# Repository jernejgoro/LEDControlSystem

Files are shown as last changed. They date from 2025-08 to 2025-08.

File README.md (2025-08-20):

# LEDControlSystem

## Overview
The **LEDControlSystem** is an integrated solution designed to control up to six independent LEDs / LED strips. This project consists of four main components: two PCB projects called **LEDcontroller** and **OfflineFlyback**, **Firmware** for the LEDcontroller and a **Web Application** for controlling the system, providing users with a seamless and intuitive way to manage their LED lighting.

---

## Components

### 1. LEDcontroller
- **Description**: An LED controller based on the Espressif ESP-WROOM-32 module with six independent output channels.
  <details>
  <summary><strong>Characteristics:</strong></summary>

  - **Input voltage range:** 5 V<sub>DC</sub> - 36 V<sub>DC</sub>
  - **Output voltage:** same as input
  - **Number of independent channels:** 6
  - **Maximum output current per channel:** 3 A
  - **Maximum total output current:** 6,5 A
  </details>

  <details>
  <summary><strong>Features:</strong></summary>

  - Dedicated mode button
  - LED indicators: power, WiFi state, error
  - Connector for programming and debugging via UART
  </details>

### 2. OfflineFlyback
- **Description:** A 24 V / 55 W SMPS based on the STM VIPERGAN50 switcher and Wurth 750343068 transformer.
- **Topology:** Isolated quasi-resonant flyback with secondary side regulation.
  <details>
  <summary><strong>Characteristics:</strong></summary>

  - **Input voltage range:** 185 V<sub>AC</sub> - 265 V<sub>AC</sub>
  - **Output voltage:** 24 V<sub>DC</sub>
  - **Maximum output power:** 55 W
  - **Efficiency at full load:** Up to 90%
  - **Idle power consumption:** < 100 mW (@ 230 V<sub>AC</sub>)
  - **Output ripple and noise:** < 70 mV<sub>pp</sub>
  </details>

  <details>
  <summary><strong>Features:</strong></summary>

  - Compact design
  - Input overvoltage protection
  - Brown-in and brown-out
  - Output overvoltage protection
  - Output overload protection
  - Embedded thermal shutdown
  </details>

### 3. Firmware
- **Description**: Custom firmware based on the ESP-IDF framework 5.4.0 and FreeRTOS designed for the LEDcontroller.
  <details>
  <summary><strong>Features:</strong></summary>

  - **Supports various LED configurations**: single-color LEDs and RGB LEDs
  - **Channel dimming method:** PWM (10 bit, 5 kHz)
  - **Smooth transitions**: seamless changes when altering the state of the output channels
  - **Supports three different WiFi modes**: disabled, client mode and access point mode
  - **Custom web API**: used to change device settings and control output channels
  </details>

### 4. Web Application
- **Description**: A user-friendly web application that allows users to interact with the LEDcontroller.
  <details>
  <summary><strong>Features:</strong></summary>

  - Real-time control of output channels
  - Real-time control of device settings via the "admin" webpage
  - Compatible with various devices (PC, tablet, smartphone)
  </details>

---

## Web API

#### GET method: 

<details>
<summary><strong>Reading device configuration:</strong></summary>

| Description | URL | Query string supported names |
|-|-|-|
| Full device configuration | http://\<_IP_>/api/conf | / |
| Number of active RGB LEDs | http://\<_IP_>/api/conf | rgb_outputs |
| Number of active single-color LEDs | http://\<_IP_>/api/conf | w_outputs |
| WiFi enable flag at device startup | http://\<_IP_>/api/conf | enable_wifi |

</details>

<details>
<summary><strong>Reading output channel status and duty cycle:</strong></summary>

| Description | URL | Query string supported names |
|-|-|-|
| Enable status and duty cycle of all active channels | http://\<_IP_>/api/ch | / |
| Enable status and duty cycle of all active channels | http://\<_IP_>/api/ch/all | / |
| Enable status of all active channels | http://\<_IP_>/api/ch/all | ch_enable |
| Duty cycle of all active channels | http://\<_IP_>/api/ch/all | ch_duty |
| Enable status of individual active channel | http://\<_IP_>/api/ch | ch<_0-5_>_enable |
| Duty cycle of individual active channel | http://\<_IP_>/api/ch | ch<_0-5_>_duty |

</details>

#### POST method: 

<details>
<summary><strong>Changing device configuration:</strong></summary>

| Description | URL | JSON key | Supported value |
|-|-|-|-|
| Number of active RGB LEDs | http://\<_IP_>/api/conf | rgb_outputs | 0 - 2 |
| Number of active single-color LEDs | http://\<_IP_>/api/conf | w_outputs | 0 - 6 |
| WiFi enable flag at device startup | http://\<_IP_>/api/conf | enable_wifi | 0, 1  |

</details>

<details>
<summary><strong>Changing WiFi credentials for client mode:</strong></summary>

| Description | URL | JSON key | Supported value |
|-|-|-|-|
| SSID | http://\<_IP_>/api/cred | WIFI_SSID | String up to 30 characters |
| Password | http://\<_IP_>/api/cred | WIFI_PASSWORD | String up to 30 characters |

</details>

<details>
<summary><strong>Changing output channel status and duty cycle:</strong></summary>

| Description | URL | JSON key | Supported value |
|-|-|-|-|
| Enable status of all active channels | http://\<_IP_>/api/ch/all | ch_enable | 0, 1 |
| Duty cycle of all active channels | http://\<_IP_>/api/ch/all | ch_duty | 0 - 1023 |
| Enable status of individual active channel | http://\<_IP_>/api/ch | ch<_0-5_>_enable | 0, 1 |
| Duty cycle of individual active channel | http://\<_IP_>/api/ch | ch<_0-5_>_duty | 0 - 1023 |

</details>

---

**Disclaimer:** This project is a work in progress. Use the files, hardware and software given in this repository **at your own risk**.

---

## License
This project (LEDControlSystem) is licensed under the GNU General Public License v3.0 - see the [LICENSE](LICENSE) file for details.

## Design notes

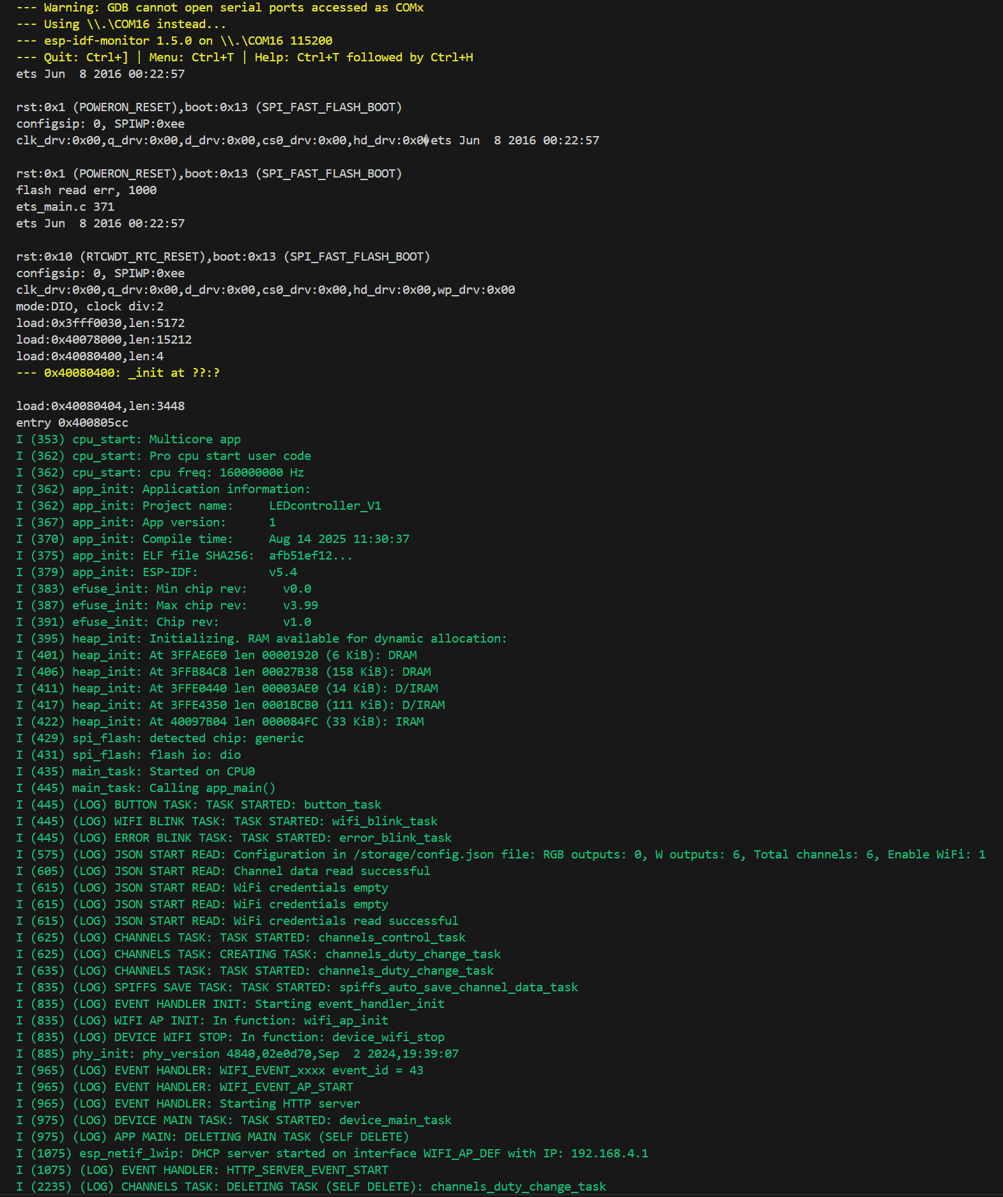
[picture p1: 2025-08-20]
firmware/LEDcontroller_V1.2.0/misc/LEDcontroller_V1.2.0_first_bootup_process.png

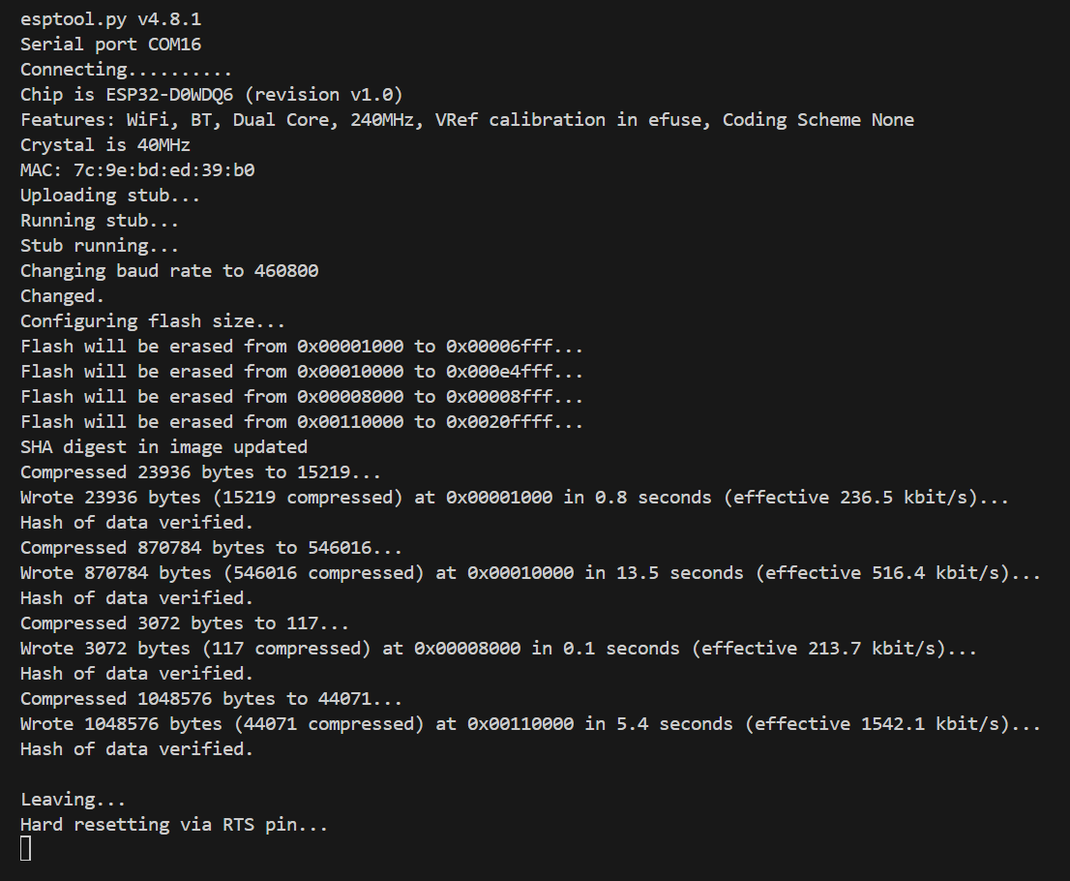
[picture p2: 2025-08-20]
firmware/LEDcontroller_V1.2.0/misc/LEDcontroller_V1.2.0_upload_process.png

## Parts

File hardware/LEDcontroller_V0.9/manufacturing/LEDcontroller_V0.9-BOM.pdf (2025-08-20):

Comment | Description | Designator | Footprint | LibRef | Quantity | Unit price /€ | Total price /€ | Unit price 10# /€ | Total price #10 /€
100n | Vishay GA0603Y104KXAAC31G | C1, C6, C7 | capacitor_smd_0603 | Capacitor - non-polarised | 3 | 0,266 | 0,80 | 0,169 | 0,51
10u | Samsung CL31B106KBHNNNE | C2 | capacitor_smd_1206 | Capacitor - non-polarised | 1 | 0,219 | 0,22 | 0,143 | 0,14
22u | TDK C2012X5R1V226M125AC | C3, C4 | capacitor_smd_0805 | Capacitor - non-polarised | 2 | 0,551 | 1,10 | 0,365 | 0,73
10u | TAIYO YUDEN TMK212BBJ106MGHT | C5 | capacitor_smd_0805 | Capacitor - non-polarised | 1 | 0,238 | 0,24 | 0,123 | 0,12
330u | Panasonic EEU-FS1V331LB | C8, C9 | capacitor_tht_3mm5_lead_8mm | Capacitor - polarised | 2 | 0,656 | 1,31 | 0,433 | 0,87
CDSOD323-T03SC | Bourns CDSOD323-T03SC | D1 | diode_smd_sod_323-2 | ESD diode | 1 | 0,665 | 0,67 | 0,500 | 0,50
green | Osram KG EELP41.22-PHRH-35-A8J8-20-R18 | D2 | led_smd_0603 | LED | 1 | 0,238 | 0,24 | 0,131 | 0,13
blue | ROHM SMLEN3BC8TT86 | D3 | led_smd_0603 | LED | 1 | 0,675 | 0,68 | 0,405 | 0,41
red | Osram KS EELP41.22-P1R2-58-A8J8-020-R18 | D4 | led_smd_0603 | LED | 1 | 0,238 | 0,24 | 0,131 | 0,13
Fuse | Bourns SF-0603HI800M-2 | F1 | resisitor_smd_0603 | Fuse | 1 | 0,466 | 0,47 | 0,413 | 0,41
15u | Bourns SRR5828A-150M | L1 | inductor_smd_5mm8_x_5mm8 | Inductor | 1 | 1,100 | 1,10 | 0,851 | 0,85
Terminal Block | Adam Tech EBAFA-02-D | P1 | terminal_block_1X2_5mm08 | Terminal Block 1X2 | 1 | 0,760 | 0,76 | 0,293 | 0,29
Terminal Block | 4x Adam Tech EBAFA-02-D | P2 | terminal_block_1X8_5mm08 | Terminal Block 1X8 | 1 | 0,760 | 0,76 | 0,293 | 0,29
Header | | P3 | header_2X3_2mm54 | Header 2X3 | 1 | | 0,00 | | 0,00
NMOS | ONSEMI FDS8949 | Q1, Q2, Q3 | generic_SO-8 | Transistor - N-MOSFET 2 ch | 3 | 1,490 | 4,47 | 0,903 | 2,71
86.6k | Panasonic ERA-3AEB8662V | R1 | resisitor_smd_0603 | Resistor | 1 | 0,095 | 0,10 | 0,055 | 0,06
30k | Panasonic ERA-3APB303V | R2 | resisitor_smd_0603 | Resistor | 1 | 0,238 | 0,24 | 0,201 | 0,20
10k | Vishay CRCW060310K0FKEI | R3 | resisitor_smd_0603 | Resistor | 1 | 0,114 | 0,11 | 0,028 | 0,03
10R | Vishay CRCW060310R0FKED | R4, R5, R6, R7, R8, R9 | resisitor_smd_0603 | Resistor | 6 | 0,114 | 0,68 | 0,028 | 0,17
1k | Vishay CRCW06031K00FKED | R10, R11, R12 | resisitor_smd_0603 | Resistor | 3 | 0,103 | 0,31 | 0,028 | 0,08
Tactile switch | Same Sky TS04-66-43-BK-160-SMT | S2 | tactile_switch_smd_6x6mm_5mm_4_pin | Switch - 4 pins V2 | 1 | 0,181 | 0,18 | 0,147 | 0,15
Test point | | TP1 | test_point | Test point | 1 | | 0,00 | | 0,00
STM DCP3601 | STM DCP3601NDMR | U1 | generic_sot23-6L | STM DCP3601 | 1 | 1,880 | 1,88 | 1,210 | 1,21
ESP-WROOM-32 | Espressif ESP-WROOM-32 | U2 | ESP-WROOM-32_no_silk | ESP-WROOM-32 | 1 | | 0,00 | | 0,00
ESDA25B1RL | STM ESDA25B1RL | U3 | generic_SO-8 | ESD diodes - 6 channels | 1 | 0,447 | 0,45 | 0,333 | 0,33
PESD3V3L5UY | Nexperia PESD3V3L5UY,115 | U5 | GENERIC_SOT363 | ESD diodes - 5 channels | 1 | 0,295 | 0,30 | 0,200 | 0,20
| | | | | | | #1 | #10
VAT /% | 22
| | | | | | | 17,28 | 10,52
| | | | | | | 3,80 | 2,31
| | | | | | | 21,09 | 12,84

Source: eu.mouser.com, date: 21. 3. 2025

Price - SUM /€
Price - VAT /€
Price - Total (SUM + VAT) /€

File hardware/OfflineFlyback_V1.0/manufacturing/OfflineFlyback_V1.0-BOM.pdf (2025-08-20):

Comment | Description | Designator | Footprint | LibRef | Quantity | Unit price /€ | Total price /€ | Unit price 10# /€ | Total price #10 /€
Bridge Rectifier 2A | Bourns CD-MBL210SL | BR1 | full_bridge_rectifier_SMD | Bridge Rectifier | 1 | 0,513 | 0,513 | 0,355 | 0,355
4n7 | TDK CD12ZU2GA472MYNKA Y1 | C1 | capacitor_tht_10mm_lead_2_slim | Capacitor - non-polarised | 1 | 0,576 | 0,576 | 0,386 | 0,386
68u | Panasonic EEU-EE2G680 | C2, C3 | capacitor_tht_7mm5_lead_18mm | Capacitor - polarised | 2 | 2,580 | 5,160 | 1,760 | 3,520
100n | Vishay / BC Components BFC233920104 X2 | C4, C5 | capacitor_tht_10mm_lead | Capacitor - non-polarised | 2 | 0,387 | 0,774 | 0,195 | 0,390
820u | Panasonic EEU-FR1V821L | C6, C7 | capacitor_tht_5mm_lead_10mm | Capacitor - polarised | 2 | 0,990 | 1,980 | 0,508 | 1,016
4n7 | Kyocera AVX 1206AC472KAT2A X7R | C8 | capacitor_smd_1206 | Capacitor - non-polarised | 1 | 0,369 | 0,369 | 0,220 | 0,220
10u | Samsung CL31B106KBHNNNE X7R | C9 | capacitor_smd_1206 | Capacitor - non-polarised | 1 | 0,180 | 0,180 | 0,108 | 0,108
22u | Wurth 860240673003 | C10 | capacitor_tht_2mm5_lead_6mm3 | Capacitor - polarised | 1 | 0,162 | 0,162 | 0,162 | 0,162
220p | Samsung CL10B221KC8WPNC X7R | C11 | capacitor_smd_0603 | Capacitor - non-polarised | 1 | 0,099 | 0,099 | 0,059 | 0,059
1u | Samsung CL10B105KB9VPJC X7R | C12 | capacitor_smd_0603 | Capacitor - non-polarised | 1 | 0,342 | 0,342 | 0,223 | 0,223
100n | Vishay / Vitramon GA0603Y104KXAAC31G X7R | C13 | capacitor_smd_0603 | Capacitor - non-polarised | 1 | 0,270 | 0,270 | 0,160 | 0,160
22n | Kyocera AVX 06035C223K4T2A X7R | C14 | capacitor_smd_0603 | Capacitor - non-polarised | 1 | 0,090 | 0,090 | 0,031 | 0,031
1n | Murata GRM1885C1H102JA01D C0G | C15 | capacitor_smd_0603 | Capacitor - non-polarised | 1 | 0,090 | 0,090 | 0,018 | 0,018
10n | Murata GCM188R71H103KA37J X7R | C16 | capacitor_smd_0603 | Capacitor - non-polarised | 1 | 0,090 | 0,090 | 0,045 | 0,045
10A | Panjit MBR10H150PC-AU_R2_007A1 | D1 | diode_TO_2787C | Diode - Schottkey | 1 | 0,828 | 0,828 | 0,560 | 0,560
300mA | Vishay 1N4148W-HG3_A-08 | D2 | diode_smd_sod_123 | Diode - silicon | 1 | 0,297 | 0,297 | 0,208 | 0,208
1kV 2A | MCC FR2M-LTP | D3 | diode_smd_smb | Diode - silicon | 1 | 0,594 | 0,594 | 0,348 | 0,348
3.15 A | Littelfuse 40013150440 3.15 A Slow Blow | F1 | fuse_tht_5mm08 | Fuse | 1 | 1,320 | 1,320 | 1,110 | 1,110
744821240 | Wurth 744821240 1.5A 4mH | L1 | wurth_common_mode_choke_4mm5_10mm | Common Mode Choke | 1 | 2,470 | 2,470 | 2,450 | 2,450
3u3 | Bourns SRP7028A-3R3M | L2 | inductor_smd_6mm6_x_7mm3 | Inductor | 1 | 0,828 | 0,828 | 0,704 | 0,704
Terminal Block | Adam Tech EBAFA-02-D | P1, P2 | terminal_block_1X2_5mm08 | Terminal Block 1X2 | 2 | 0,585 | 1,170 | 0,433 | 0,866
2M | Vishay / Draloric RCV12062M00JNEA | R1 | resisitor_smd_1206 | Resistor | 1 | 0,216 | 0,216 | 0,110 | 0,110
62k | Panasonic ERJ-UP8F6202V | R2, R3 | resisitor_smd_1206 | Resistor | 2 | 0,225 | 0,450 | 0,080 | 0,160
10M | ROHM KTR25JZPF1005 | R4 | resisitor_smd_1210 | Resistor | 1 | 0,297 | 0,297 | 0,135 | 0,135
10R | Vishay CRCW060310R0FKED | R5 | resisitor_smd_0603 | Resistor | 1 | 0,135 | 0,135 | 0,068 | 0,068
820k | Walsin MR06X8203FTL | R6 | resisitor_smd_0603 | Resistor | 1 | 0,140 | 0,140 | 0,022 | 0,022
510k | Bourns CR0603-FX-5103ELF | R7 | resisitor_smd_0603 | Resistor | 1 | 0,090 | 0,090 | 0,020 | 0,020
1k6 | Bourns CR0603-FX-1601ELF | R8 | resisitor_smd_0603 | Resistor | 1 | 0,090 | 0,090 | 0,012 | 0,012
130k | Panasonic ERJ-3RED1303V 0.5% | R9, R13 | resisitor_smd_0603 | Resistor | 2 | 0,126 | 0,252 | 0,125 | 0,250
10k | Vishay / Dale CRCW060310K0FKEI | R10 | resisitor_smd_0603 | Resistor | 1 | 0,135 | 0,135 | 0,068 | 0,068
0R | Royalohm CQ03WAF0000T5E | R11 | resisitor_smd_0603 | Resistor | 1 | 0,001 | 0,001 | 0,001 | 0,001
7k68 | Panasonic ERA-3AEB7681V 0.1% | R12 | resisitor_smd_0603 | Resistor | 1 | 0,090 | 0,090 | 0,049 | 0,049
100k | Yageo AC0603FR-7W100KL | R14 | resisitor_smd_0603 | Resistor | 1 | 0,243 | 0,243 | 0,024 | 0,024
47k | Bourns CR0603-FX-4702ELF | R15 | resisitor_smd_0603 | Resistor | 1 | 0,090 | 0,090 | 0,014 | 0,014
88k7 | Walsin WR06X8872FTL | R16 | resisitor_smd_0603 | Resistor | 1 | 0,140 | 0,140 | 0,025 | 0,025
15k | DO NOT PLACE | R17 | resisitor_smd_0603 | Resistor | 1 | | 0,000 | | 0,000
30k | Wurth 560112116107 | R18 | resisitor_smd_0603 | Resistor | 1 | 0,099 | 0,099 | 0,092 | 0,092
NTC 2R2 | Epcos / TDK B57237S0229M000 | RT1 | thermistor_tht_7mm5 | Thermistor | 1 | 0,855 | 0,855 | 0,788 | 0,788
275V 25A | Epcos / TDK B72210S0271K101 | RV1 | varistor_tht_7mm5 | Varistor | 1 | 0,504 | 0,504 | 0,257 | 0,257
WURTH_750343004 | | T1 | WURTH_10_PIN_750343004 | Wurth - 10 pins - 750343004 | 1 | 8,940 | 8,940 | 8,060 | 8,060
VIPERGAN50 | | U1 | VIPERGAN50TR_V2 | VIPERGAN50 V3 | 1 | 3,070 | 3,070 | 2,310 | 2,310
63% - 125% | Vishay VO615C-2X019T | U2 | SMD-4 | Optocoupler | 1 | 0,720 | 0,720 | 0,499 | 0,499
1.24V | STM TS3431AILT | VR1 | generic_sot23-3L | Programmable Shunt Voltage Reference | 1 | 1,060 | 1,060 | 0,648 | 0,648
| | | | | | | #1 | #10
VAT /% | 22
| | | | | | | 35,82 | 26,55
| | | | | | | 7,88 | 5,84
Price - Total (SUM + VAT) /€ | 43,70 | 32,39

Source: eu.mouser.com, date: 24. 6. 2025

Price - SUM /€
Price - VAT /€

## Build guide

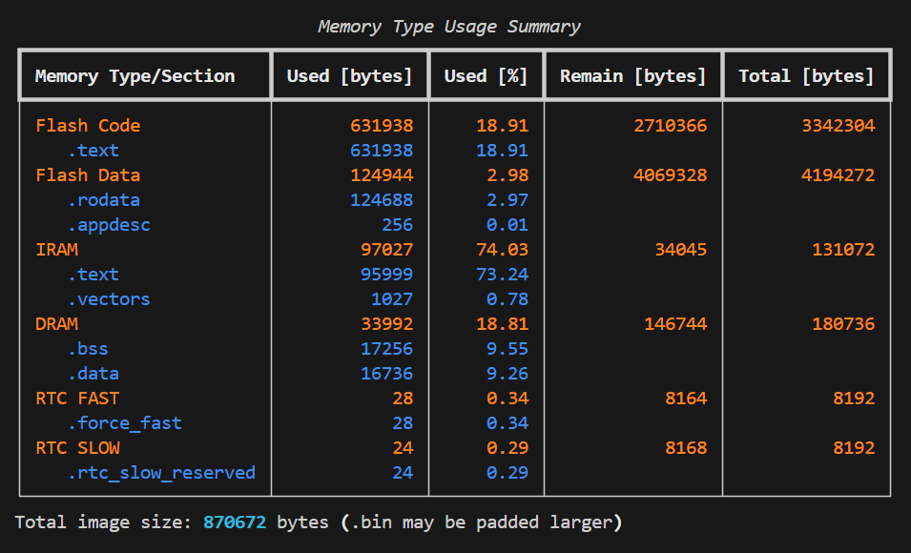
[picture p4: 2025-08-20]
firmware/LEDcontroller_V1.2.0/misc/LEDcontroller_V1.2.0_memory_usage.png

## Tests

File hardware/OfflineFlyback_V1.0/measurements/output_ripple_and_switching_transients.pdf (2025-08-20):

## Output ripple and switching transients

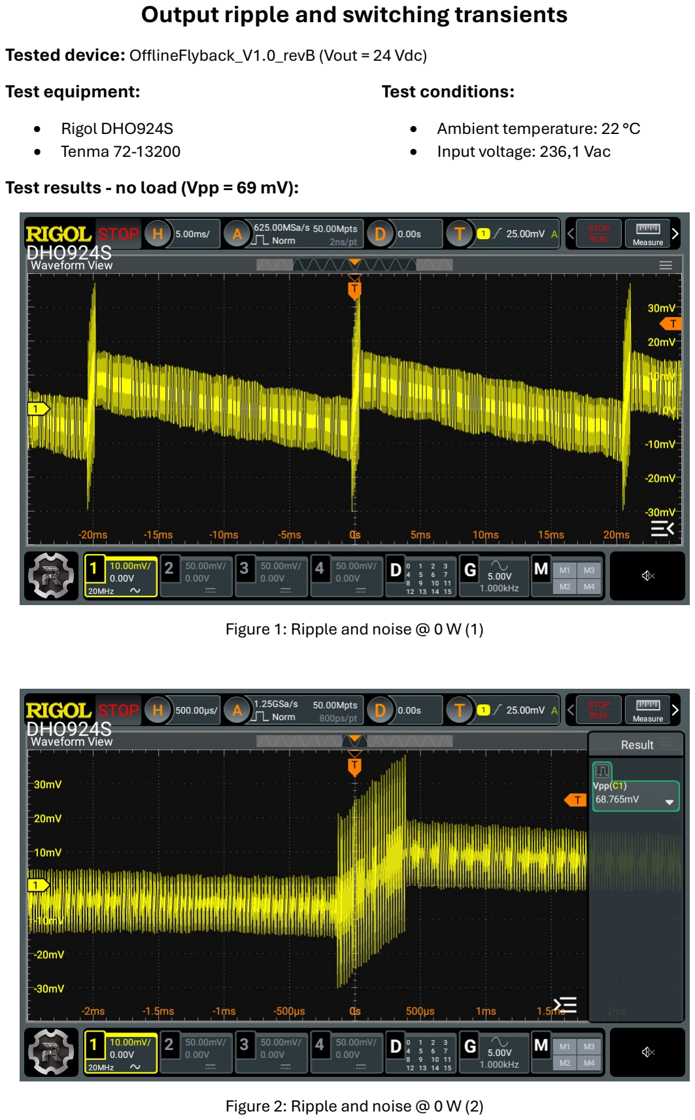
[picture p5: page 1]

Tested device: OfflineFlyback_V1.0_revB (Vout = 24 Vdc) Test equipment:

- Rigol DHO924S
- Tenma 72-13200

Test conditions:

- Ambient temperature: 22 °C
- Input voltage: 236,1 Vac Test results - no load (Vpp = 69 mV):

Figure 1: Ripple and noise @ 0 W (1)

Figure 2: Ripple and noise @ 0 W (2)

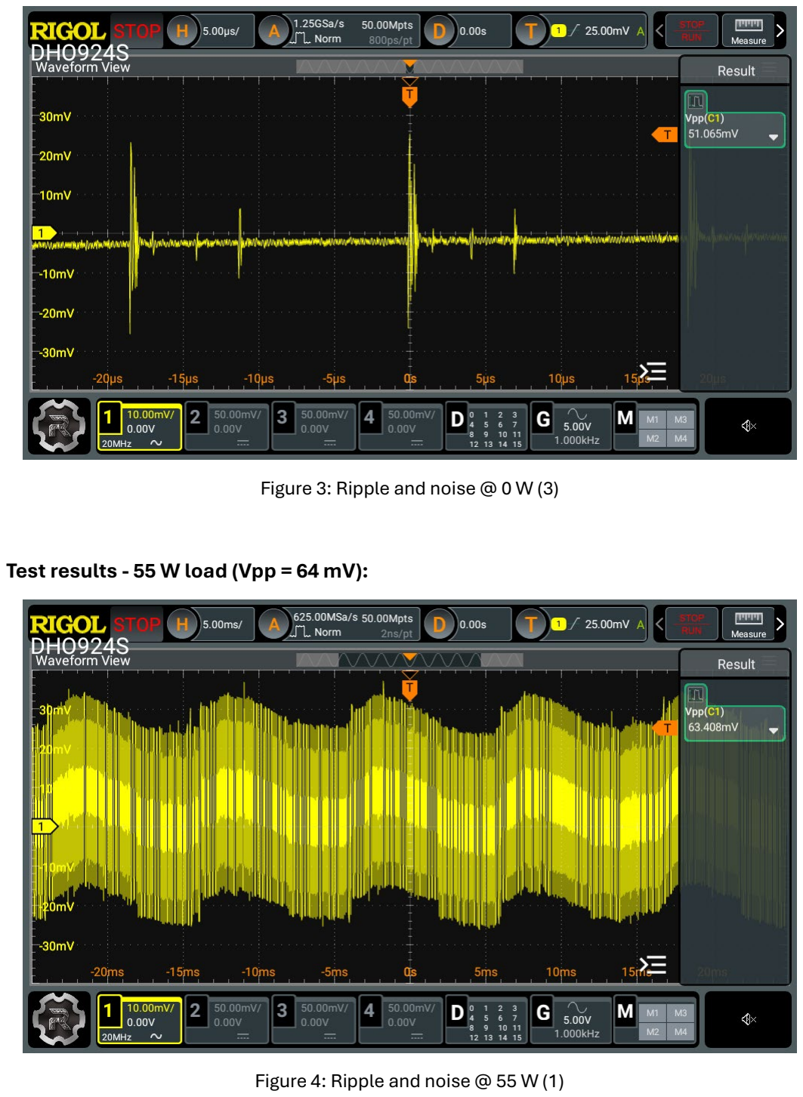
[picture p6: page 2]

Figure 3: Ripple and noise @ 0 W (3)

Test results - 55 W load (Vpp = 64 mV):

Figure 4: Ripple and noise @ 55 W (1)

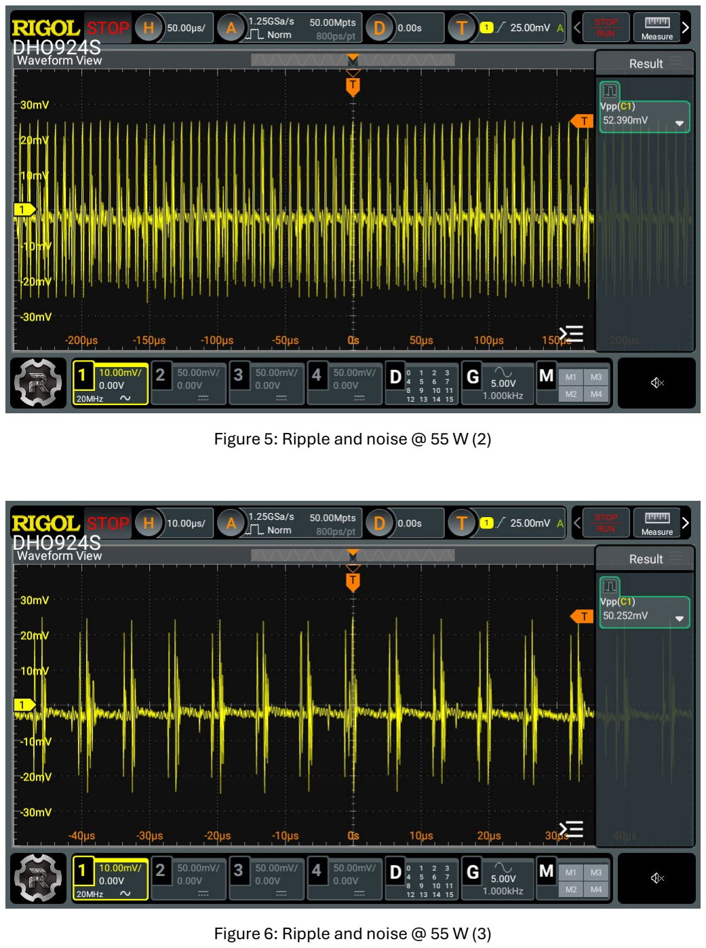
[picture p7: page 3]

Figure 5: Ripple and noise @ 55 W (2)

Figure 6: Ripple and noise @ 55 W (3)

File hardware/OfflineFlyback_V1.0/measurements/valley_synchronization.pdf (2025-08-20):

## Valley synchronization

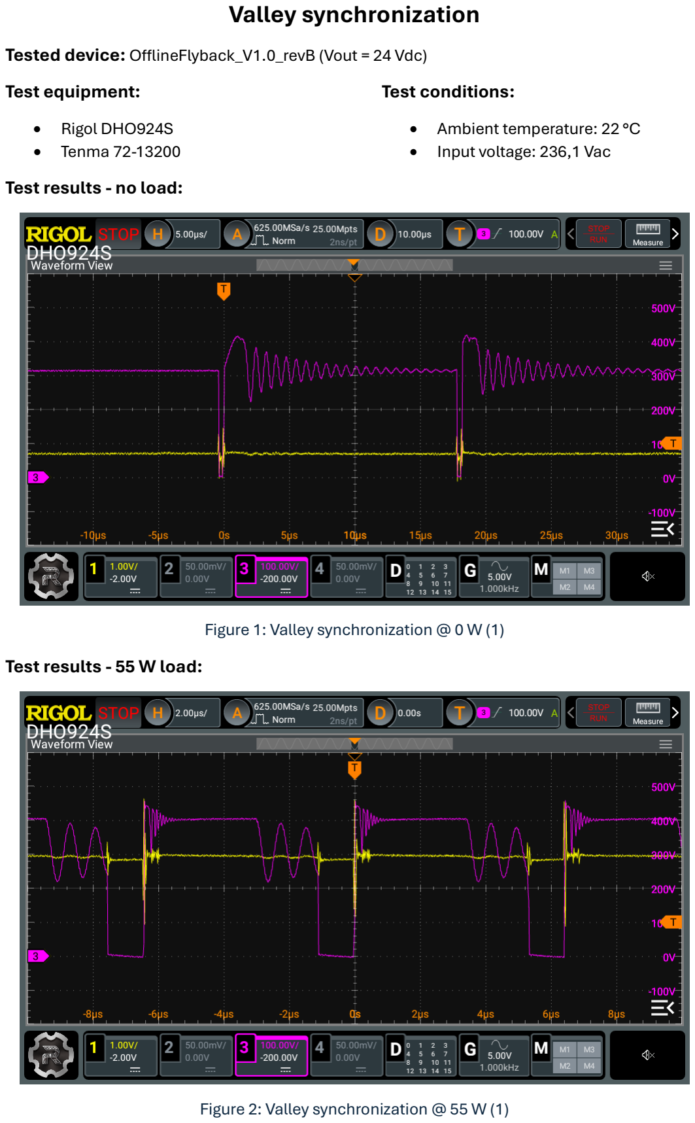
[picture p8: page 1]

Tested device: OfflineFlyback_V1.0_revB (Vout = 24 Vdc) Test equipment:

- Rigol DHO924S
- Tenma 72-13200

Test conditions:

- Ambient temperature: 22 °C
- Input voltage: 236,1 Vac Test results - no load:

Figure 1: Valley synchronization @ 0 W (1) Test results - 55 W load:

Figure 2: Valley synchronization @ 55 W (1)

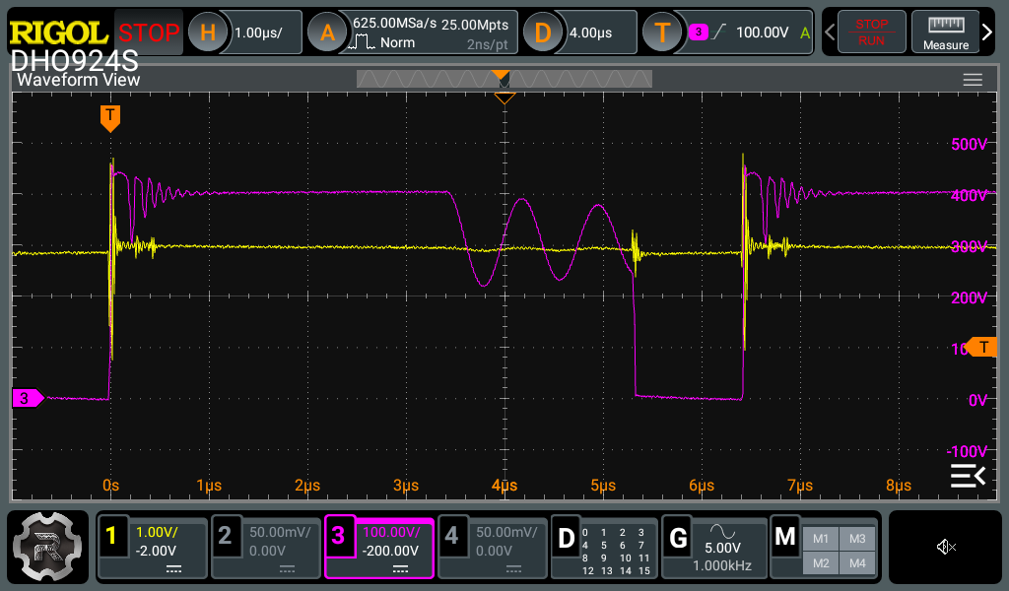
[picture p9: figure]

Figure 3: Valley synchronization @ 55 W (2)

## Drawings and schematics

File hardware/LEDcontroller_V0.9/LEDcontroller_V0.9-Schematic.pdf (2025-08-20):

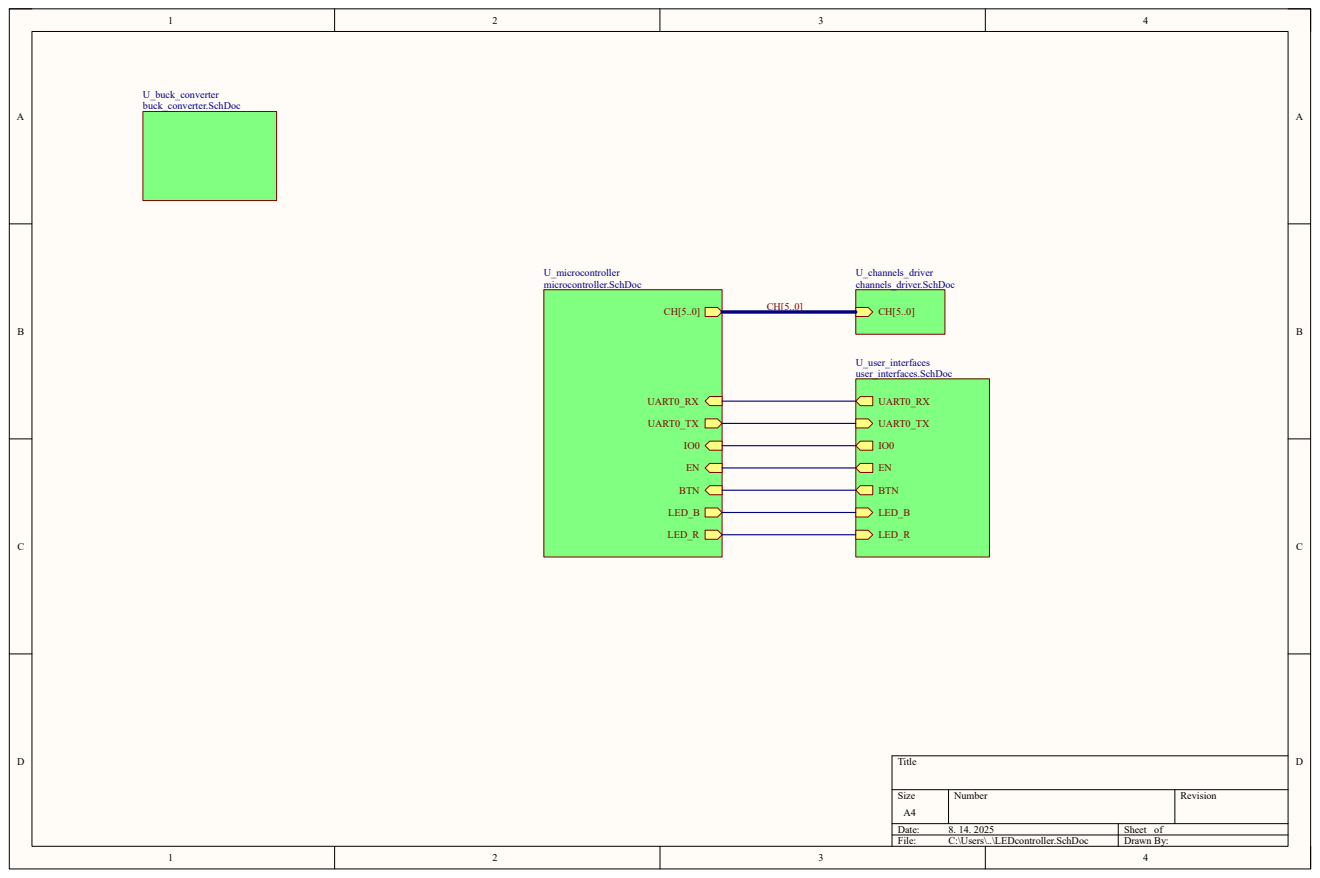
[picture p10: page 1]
Title; U_buck_converter buck_converter.SchDoc; UART0_TX; UART0_RX; BTN; LED_R; LED_B; U_microcontroller microcontroller.SchDoc; U_channels_driver channels_driver.SchDoc; U_user_interfaces user_interfaces.SchDoc

Size A4 | Number | Revision

Date: 8. 14. 2025 | Sheet of
File: C:\Users\..\LEDcontroller.SchDoc | Drawn By:

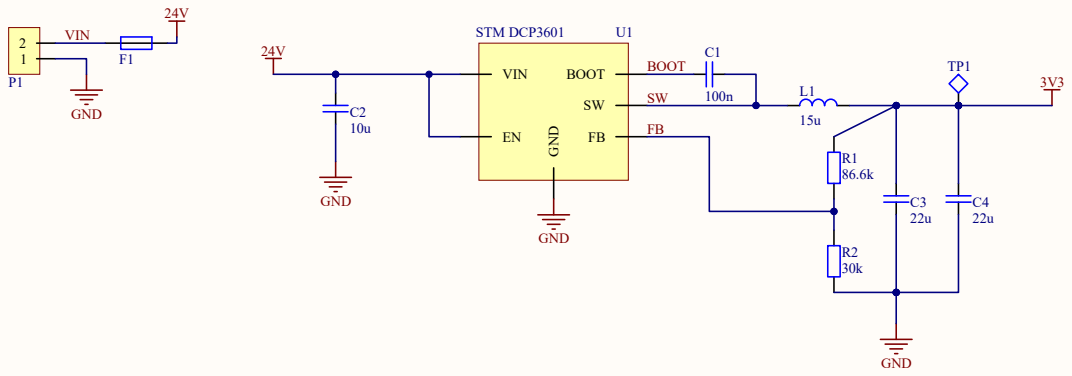
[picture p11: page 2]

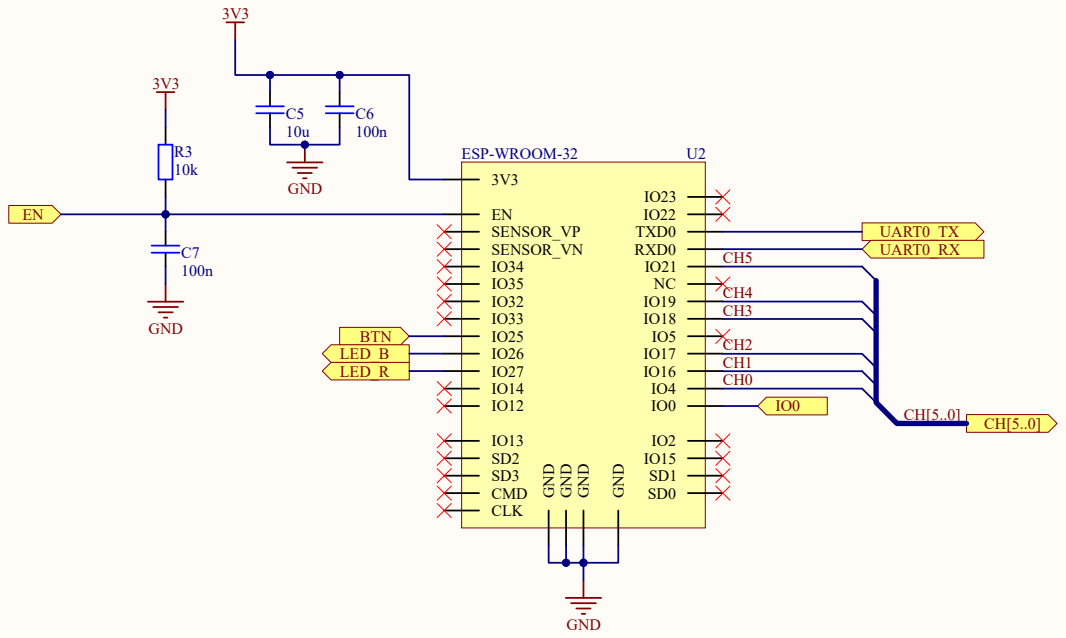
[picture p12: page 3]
Title; Size; Number; Revision; File:; C:\Users\..\microcontroller.SchDoc; Drawn By:; GND; EN SENSOR_VP SENSOR_VN IO34 IO35 IO32 IO33 IO25 IO26 IO27 IO14 IO12; IO13 SD2 SD3 CMD CLK; RXD0; TXD0; ESP-WROOM-32; UART0_TX UART0_RX; BTN LED_B LED_R

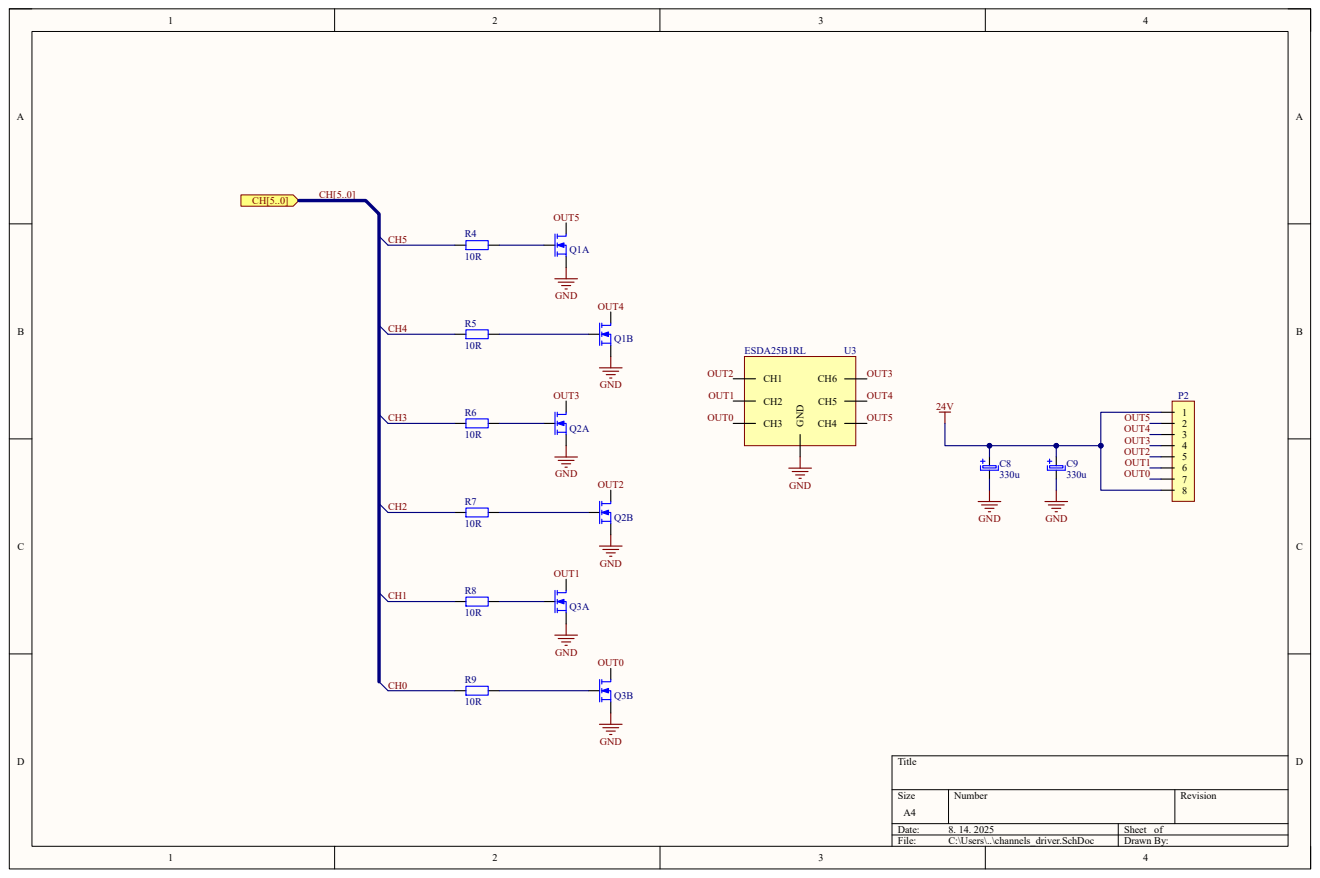
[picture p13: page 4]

# PROGRAMMING PORT

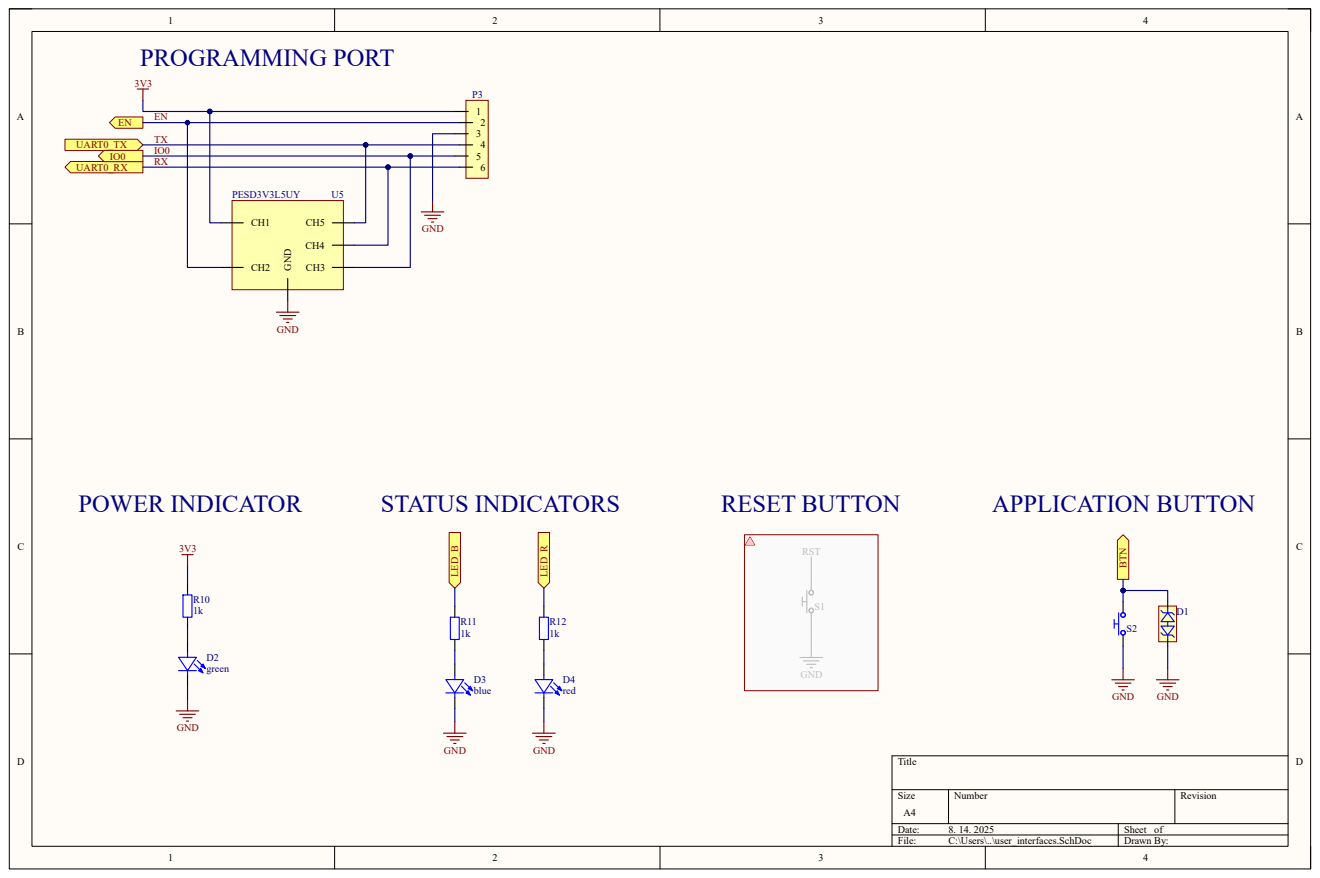
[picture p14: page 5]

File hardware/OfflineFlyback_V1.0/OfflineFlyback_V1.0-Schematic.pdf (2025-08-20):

## INPUT STAGE

HIGH VOLTAGE | LOW VOLTAGE

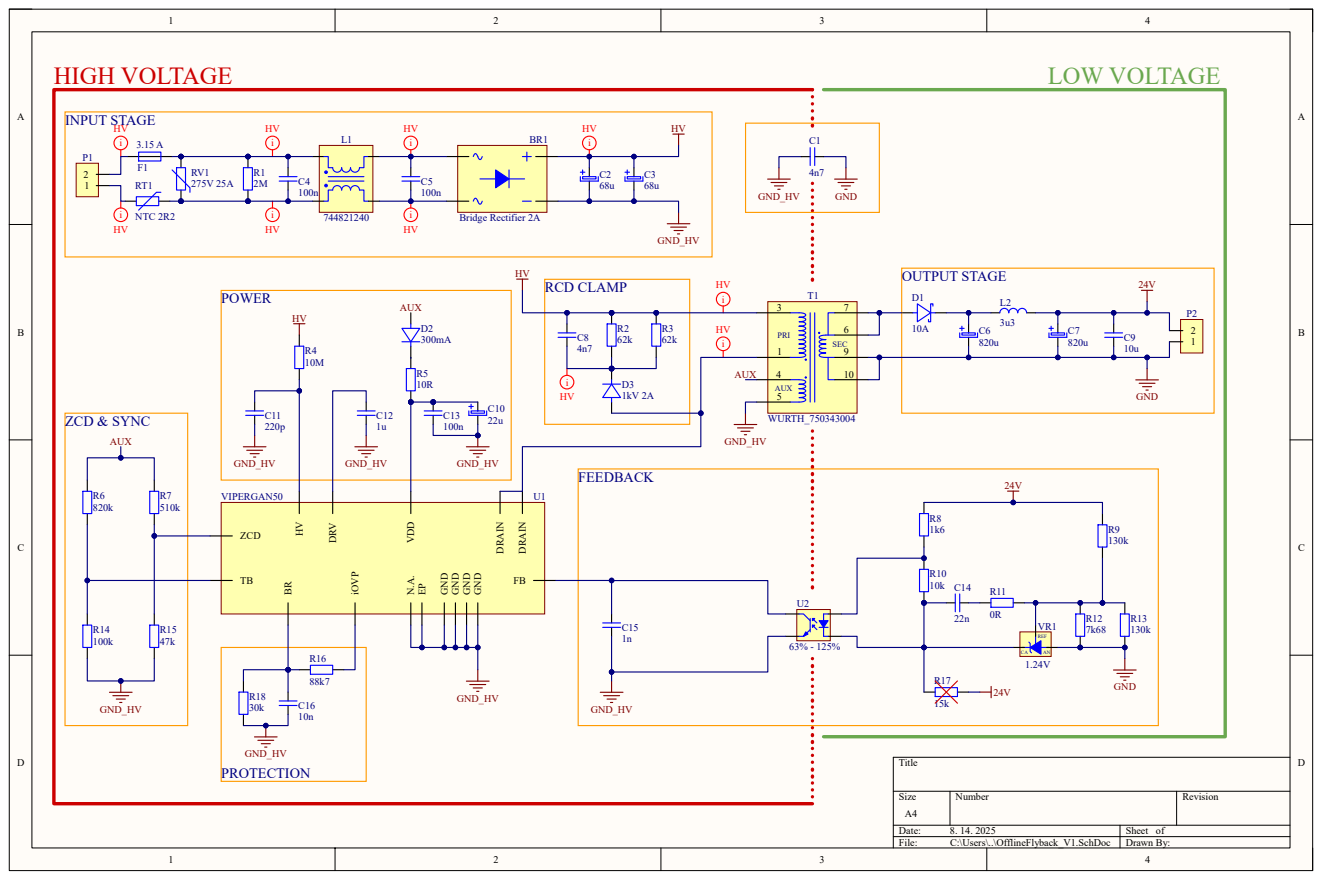
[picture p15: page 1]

Size A4 | Number | Revision

Date: 8. 14. 2025 | Sheet of
File: C:\Users\..\OfflineFlyback_V1.SchDoc | Drawn By:

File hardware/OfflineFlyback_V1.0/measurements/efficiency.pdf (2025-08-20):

### EFFICIENCY: OfflineFlyback_V1.0_revB (Vout = 24 Vdc)

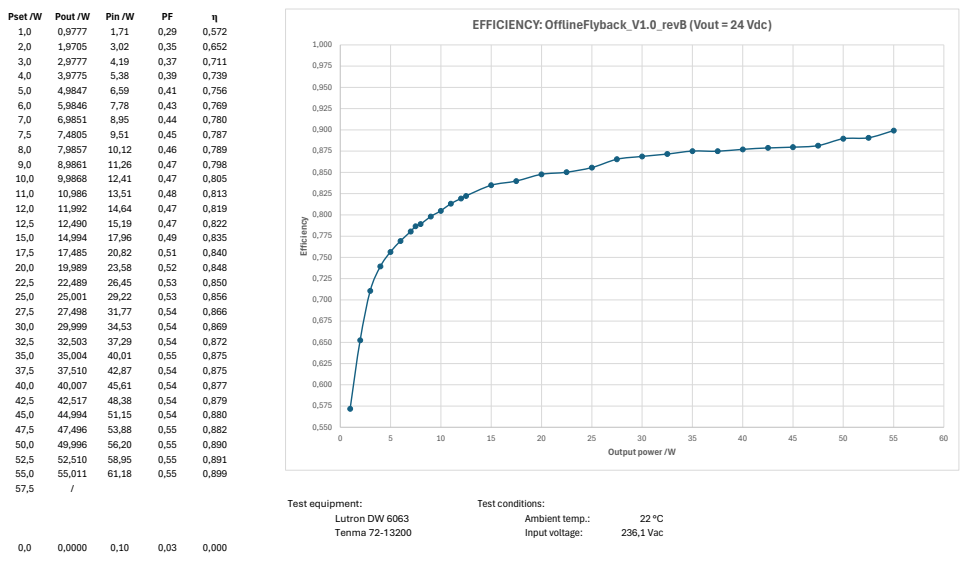
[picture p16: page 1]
Pset /W Pout /W; Pin /W; Test equipment:; Test conditions:; Lutron DW 6063; Ambient temp.:; Tenma 72-13200; Input voltage:; 236,1 Vac; 60 Efficiency; Output power /W

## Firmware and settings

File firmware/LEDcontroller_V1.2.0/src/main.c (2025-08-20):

/***************************************************************************************************************/
/** LED CONTROLLER
 * VERSION: 1.2.0
 * AUTHOR: Jernej
 * DATE: 08 2025
 * ESPIDF: framework 5.4.0
 *
 * TODO: (version 1.3)
 *  Edit "API HTTP respond messages"
 *  Edit ESP_LOGI messages
 *  Look if all variable types are as they should be (uint8_t, uint16_t, char, ...)
 *  Optimise vTaskDelay() times (Add idle task handler and look/measure its active time)
 *  Edit HTTP respond codes and messages (httpd_resp_send(), httpd_resp_send_404(), ...)
 *
 * TODO: (version 2.0)
 *  Rewrite http server event handlers (use wildcard for POST requests)
 *  Assign tasks to specific core
 *  Use Semaphores / Mutexs / Custom dirty flags if they are needed
 *  Change IP for AP mode
 *  Implement "captive portal" in AP mode (automatically open admin webpage when smartphone connects to AP)
 *  Possible upgrades: task for IR remote controller, e-fuse for default AP credentials
 *
 * NOTES:
 *  "freertos/FreeRTOSConfig.h"
 *  Preemption = 1
 *  Time Slicing = 1
 *  => Rund Robin (for tasks with the same priority)
 *
 *  WIFI runs on core 0
 *  app_main() runs on core 0
 *  other tasks and handlers are dynamicly assined to core 0 or 1
 *
 *  (GET)
 *      curl "http://10.169.50.11/api/ch?ch0_duty&ch1_duty&ch2_enable&ch5_enable&ch5_duty"
 *      curl "http://10.169.50.11/api/ch/all?ch_duty"
 *      curl "http://10.169.50.11/api/conf?rgb_outputs&w_outputs&enable_wifi"
 *
 *  (POST)
 *      curl -H "Content-Type: application/json" -X POST 10.169.50.11/api/ch -d "{\"ch4_enable\":1,\"ch0_enable\":0,\"ch3_duty\":299,\"ch5_duty\":399}"
 *      curl -H "Content-Type: application/json" -X POST 10.169.50.11/api/ch/all -d "{\"ch_enable\":1,\"ch_duty\":100}"
 *      curl -H "Content-Type: application/json" -X POST 10.169.50.11/api/conf -d "{\"w_outputs\":5,\"rgb_outputs\":0,\"enable_wifi\":0}"
 *      curl -H "Content-Type: application/json" -X POST 10.169.50.11/api/cred -d "{\"WIFI_SSID\":\"ssid\",\"WIFI_PASSWORD\":\"asswd\"}"
 *      curl -H "Content-Type: application/json" -X POST 10.169.50.11/api/reboot -d "{}"
 *
 *  CONFIG_LWIP_LOCAL_HOSTNAME "espressif" in sdkconfig.h
 *  CONFIG_ESP_WIFI_TASK_PINNED_TO_CORE_0 1 in sdkconfig.h
 *
 * LINKS:
 *  (WIFI) https://esp32tutorials.com/esp32-esp-idf-connect-wifi-station-mode-example/
 *  (LOGGING) https://docs.espressif.com/projects/esp-idf/en/v5.2/esp32/api-reference/system/log.html
 *  (WINDOWS POST) https://stackoverflow.com/questions/11834238/curl-post-command-line-on-windows-restful-service
 */
/***************************************************************************************************************/
/*** INCLUDED LIBRARIES ****************************************************************************************/

#include "ledc_common.h"
#include "ledc_variables.h"
#include "ledc_functions.h"
#include "ledc_tasks.h"

/***************************************************************************************************************/
/*** MAIN TASK aka DEVICE BOOTUP PROCESS ***********************************************************************/

void app_main(void) // COMPLETE
{
    // printf("app_main running on core %d\n\r", xPortGetCoreID());

    /*** DISABLE LOGGING ***/
    esp_log_level_set("wifi_init", ESP_LOG_NONE);
    esp_log_level_set("wifi", ESP_LOG_NONE);
    esp_log_level_set("gpio", ESP_LOG_NONE);
    // esp_log_level_set(TAG_APP_MAIN, ESP_LOG_NONE);
    // esp_log_level_set("*", ESP_LOG_NONE);    // Disable all

    /***********************************************************************************************************/
    /*** DEVICE BOOTUP PROCESS *********************************************************************************/

    /*** GPIO INIT ***/
    if (gpio_init() != GPIO_INIT_OK)
    {
        // Critical error -> Task should be deleted
        error_handler_function(CRITICAL_ERROR_GPIO);
        ESP_LOGW(TAG_APP_MAIN, "DELETING MAIN TASK (SELF DELETE) after gpio_init");
        vTaskDelete(NULL);
    }

    // Create button_task
    xTaskCreate(button_task, "button_tsk", 4096, NULL, 5, &ButtonTaskHandle);

    /*** DEVICE FACTORY RESET ***/
    // If button pressed at boot/reboot -> go to factory reset mode
    if (gpio_get_level(GPIO_BUTTON_1) == GPIO_BUTTON_PRESSED_VALUE)
    {
        factory_reset_status.state = FACTORY_RESET_STATE_BEGIN;
        xTaskCreate(factory_reset_blink_task, "reset_blnk_tsk", 4096, NULL, 5, &FactoryResetBlinkTaskHandle);
        vTaskDelay(pdMS_TO_TICKS(1000));

        // Wait for button to be released and in the meantime change the states of factory reset process
        while (device_button_status.button_state == BUTTON_STATE_PRESSED)
        {
            vTaskDelay(pdMS_TO_TICKS(100));
            if (device_button_status.button_pressed_ms >= FACTORY_RESET_MIN_TIME_MS)
            {
                factory_reset_status.state = FACTORY_RESET_STATE_VALID;
                break;
            }
        }
        while (device_button_status.button_state == BUTTON_STATE_PRESSED)
        {
            vTaskDelay(pdMS_TO_TICKS(100));
            if (device_button_status.button_pressed_ms > (FACTORY_RESET_MIN_TIME_MS + FACTORY_RESET_WINDOW_TIME_MS))
            {
                factory_reset_status.state = FACTORY_RESET_STATE_INVALID;
                break;
            }
        }
        while (device_button_status.button_state == BUTTON_STATE_PRESSED)
        {
            vTaskDelay(pdMS_TO_TICKS(100));
        }

        // Factory reset device if button press duration is within the limits
        if (factory_reset_status.state == FACTORY_RESET_STATE_VALID)
        {
            ESP_LOGI(TAG_APP_MAIN, "Starting factory reset process");
            factory_reset_status.state = FACTORY_RESET_STATE_RESETTING;

            // This delay is added to make LED flashing at least 5 sec long because
            // factory_reset_function() should take very little time if SPIFFS formating is disabled
            vTaskDelay(pdMS_TO_TICKS(5000));

            if (factory_reset_function() == FACTORY_RESET_OK)
            {
                factory_reset_status.state = FACTORY_RESET_STATE_COMPLETE;
                ESP_LOGI(TAG_APP_MAIN, "Rebooting in 3 seconds");
                vTaskDelay(pdMS_TO_TICKS(3000));
                esp_restart();
            }
            // If factory reset function failed -> go to error state and delete main task
            ESP_LOGE(TAG_APP_MAIN, "Error: factory_reset_function. CANNOT FACTORY RESET DEVICE");
            factory_reset_status.state = FACTORY_RESET_STATE_ERROR;
            ESP_LOGW(TAG_APP_MAIN, "DELETING MAIN TASK (SELF DELETE) after factory_reset_function");
            vTaskDelete(NULL);
        }
        // Skip factory reset if button press duration is NOT within the limits
        ESP_LOGI(TAG_APP_MAIN, "Factory reset process NOT started");
        factory_reset_status.state = FACTORY_RESET_STATE_ABORT;

        ESP_LOGI(TAG_APP_MAIN, "Waiting factory_reset_blink_task to delete itself");
        while (FactoryResetBlinkTaskHandle != NULL)
        {
            vTaskDelay(pdMS_TO_TICKS(500));
        }
    }

    // Create wifi_blink_task
    xTaskCreate(wifi_blink_task, "wifi_blnk_tsk", 4096, NULL, 5, &WifiBlinkTaskHandle);

    // Create error_blink_task
    xTaskCreate(error_blink_task, "error_blnk_tsk", 4096, NULL, 5, &ErrorBlinkTaskHandle);

    /*** NVS INIT ***/
    // Storage for WiFi data
    if (nvs_init() != NVS_INIT_OK)
    {
        error_handler_function(CRITICAL_ERROR_NVS);

        // Error -> WiFi cannot function anymore -> reset wifi_hw_init_flag "flag"
        device_wifi_status.wifi_hw_init_flag = 0;

        // Register new error for error_blink_task
        device_error_status.new_error_level = ERROR_LEVEL_WIFI;
        device_error_status.new_error_flag = 1;
    }

    /*** SPIFFS INIT ***/
    // General storage
    if (spiffs_init() != SPIFFS_INIT_OK)
    {
        error_handler_function(CRITICAL_ERROR_SPIFFS);

        // Register new error for error_blink_task
        device_error_status.new_error_level = ERROR_LEVEL_CRITICAL;
        device_error_status.new_error_flag = 1;

        // Critical error -> Task should be deleted
        ESP_LOGW(TAG_APP_MAIN, "DELETING MAIN TASK (SELF DELETE) after spiffs_init");
        vTaskDelete(NULL);
    }

    /*** JSON START READ ***/
    // read WiFi credentials and DUTY & ENABLE values for LED channels
    if (json_start_read() != JSON_START_READ_OK)
    {
        error_handler_function(CRITICAL_ERROR_JSON);

        // Register new error for error_blink_task
        device_error_status.new_error_level = ERROR_LEVEL_CRITICAL;
        device_error_status.new_error_flag = 1;

        // Critical error -> Task should be deleted
        ESP_LOGW(TAG_APP_MAIN, "DELETING MAIN TASK (SELF DELETE) after json_start_read");
        vTaskDelete(NULL);
    }

    /*** PWM INIT ***/
    if (pwm_init() != PWM_INIT_OK)
    {
        error_handler_function(CRITICAL_ERROR_PWM);

        // Register new error for error_blink_task
        device_error_status.new_error_level = ERROR_LEVEL_CRITICAL;
        device_error_status.new_error_flag = 1;

        // Critical error -> Task should be deleted
        ESP_LOGW(TAG_APP_MAIN, "DELETING MAIN TASK (SELF DELETE) after pwm_init");
        vTaskDelete(NULL);
    }

    // Create channels_control_task
    xTaskCreate(channels_control_task, "ch_cntrl_tsk", 4096, NULL, 5, &ChannelsControlTaskHandle);
    // vTaskDelay is needed for channels_control_task to start channels_duty_change_task for the first time before it may be deleted by error_handler_function
    vTaskDelay(pdMS_TO_TICKS(200));

    // Create spiffs_auto_save_channel_data_task
    xTaskCreate(spiffs_auto_save_channel_data_task, "auto_save_tsk", 4096, NULL, 5, &SpiffsAutoSaveTaskHandle);

    // If WiFi hardware initialization successful
    if (device_wifi_status.wifi_hw_init_flag)
    {
        /*** EVENT HANDLER INIT ***/
        if (event_handler_init() != EVENT_HANDLER_INIT_OK)
        {
            error_handler_function(CRITICAL_ERROR_EVENT_HANDLER);

            // Error -> WiFi cannot function anymore -> reset wifi_hw_init_flag "flag"
            device_wifi_status.wifi_hw_init_flag = 0;

            // Register new error for error_blink_task
            device_error_status.new_error_level = ERROR_LEVEL_WIFI;
            device_error_status.new_error_flag = 1;
        }
    }

    // If WiFi hardware init was successful and WiFi is enabled by user (in config.json file) and credentials are not empty -> start WiFI in STATION mode
    if (device_wifi_status.wifi_hw_init_flag && device_conf.enable_wifi && !device_wifi_status.wifi_credentials_empty_flag)
    {
        device_wifi_station_start();
    }
    // If WiFi hardware init was successful and WiFi is enabled by user (in config.json file) and credentials are empty -> start WiFI in AP mode (should happen at factory reset / first boot)
    else if (device_wifi_status.wifi_hw_init_flag && device_conf.enable_wifi && device_wifi_status.wifi_credentials_empty_flag)
    {
        device_wifi_ap_start();
    }

    // If WiFi hardware init was successful -> create device_main_task
    if (device_wifi_status.wifi_hw_init_flag)
    {
        xTaskCreate(device_main_task, "dev_main_tsk", 4096, NULL, 5, &DeviceMainTaskHandle);
    }

    // Delete app_main
    ESP_LOGI(TAG_APP_MAIN, "DELETING MAIN TASK (SELF DELETE)");
    vTaskDelete(NULL);
}

/***************************************************************************************************************/
/*** END *******************************************************************************************************/
/***************************************************************************************************************/

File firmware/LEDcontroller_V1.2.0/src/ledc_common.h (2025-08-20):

#ifndef LEDC_COMMON_H
#define LEDC_COMMON_H
/***************************************************************************************************************/
/*** INCLUDED LIBRARIES ****************************************************************************************/

/*** FREERTOS ***/
#include "freertos/FreeRTOS.h"
#include "freertos/task.h"

/*** WIFI ***/
#include "esp_wifi.h"

/*** HTTP SERVER ***/
#include "esp_http_server.h"

/*** GPIO & PERIPHERALS ***/
#include "driver/gpio.h"
#include "driver/ledc.h" // Channels PWM control

/*** STORAGE ***/
#include "nvs_flash.h"  // NVS partition for WiFi credentials
#include "esp_spiffs.h" // SPIFFS partition for data storage

/*** JSON ***/
#include "cJSON.h"

/*** LOGGING ***/
#include "esp_log.h"

/***************************************************************************************************************/
/*** DEFINITIONS ***********************************************************************************************/

/*** EVENT HANDLER ***/
// Return values
#define EVENT_HANDLER_INIT_OK 0
#define EVENT_HANDLER_INIT_ERROR 1

/*** WIFI ***/
// Configuration
#define WIFI_AUTHMODE_TRESHOLD WIFI_AUTH_WPA2_PSK
#define WIFI_RECONNECTING_ATTEMPTS 3
// Return values
#define WIFI_STATION_INIT_OK 0
#define WIFI_STATION_INIT_ERROR 1
#define WIFI_AP_INIT_OK 0
#define WIFI_AP_INIT_ERROR 1
// WiFi modes
#define DEVICE_WIFI_MODE_NONE 0
#define DEVICE_WIFI_MODE_AP 1
#define DEVICE_WIFI_MODE_STATION 2

/*** HTTP SERVER ***/
// Configuration
#define HTTP_SERVER_PORT 80
#define HTTP_MAX_REQUEST_LEN 100
#define HTTP_MAX_RESPOND_LEN 600
#define HTTP_MAX_POST_DATA_LEN 400
#define HTTP_SERVER_MAX_URI_HANDLERS 15
#define HTTP_MAX_URI_LEN HTTPD_MAX_URI_LEN
// Return values
#define START_HTTP_SERVER_OK 0
#define START_HTTP_SERVER_ERROR 1

/*** GPIO & PERIPHERALS ***/
// Configuration
#define PWM_FREQ 5000
#define PWM_RESOLUTION 10
#define PWM_FADE_TIME_MS 1500
#define PWM_TRANSITION_STEPS 150
// GPIOs for LED indicators
#define GPIO_LED_WIFI 26  // GPIO number to which BLUE LED is connected
#define GPIO_LED_ERROR 27 // GPIO number to which RED LED is connected
// GPIOs for buttons
#define GPIO_BUTTON_1 25             // GPIO number to which BUTTON is connected
#define GPIO_BUTTON_PRESSED_VALUE 0  // GPIO value when button is pressed
#define GPIO_BUTTON_RELEASED_VALUE 1 // GPIO value when button is released
// Button states
#define BUTTON_STATE_ERROR 0
#define BUTTON_STATE_PRESSED 1
#define BUTTON_STATE_RELEASED 2
#define BUTTON_STATE_POSEDGE 3
#define BUTTON_STATE_NEGEDGE 4
// GPIOs for PWM channels
#define GPIO_CH_0 4
#define GPIO_CH_1 16
#define GPIO_CH_2 17
#define GPIO_CH_3 18
#define GPIO_CH_4 19
#define GPIO_CH_5 21
// PWM channels
#define PWM_CH_0 LEDC_CHANNEL_0
#define PWM_CH_1 LEDC_CHANNEL_1
#define PWM_CH_2 LEDC_CHANNEL_2
#define PWM_CH_3 LEDC_CHANNEL_3
#define PWM_CH_4 LEDC_CHANNEL_4
#define PWM_CH_5 LEDC_CHANNEL_5
// Return values
#define GPIO_INIT_OK 0
#define GPIO_INIT_ERROR 1
#define PWM_INIT_OK 0
#define PWM_INIT_ERROR 1

/*** JSON ***/
// Configuration
#define JSON_CONFIG_FILE_CH_DATA_PATH "/storage/channel_data.json"         // Stores channels last values
#define JSON_CONFIG_FILE_WIFI_CREDENTIALS_PATH "/storage/credentials.json" // Stores WiFi credentials
#define JSON_CONFIG_FILE_CONFIGURATION_PATH "/storage/config.json"         // Stores configuration
#define JSON_CONFIG_FILE_MAX_LEN 400
// Return values
#define JSON_START_READ_OK 0
#define JSON_START_READ_ERROR 1

/*** STORAGE ***/
// Configuration
#define SPIFFS_PARTITION_BASE_PATH "/storage" // Name of SPIFFS partition
#define SPIFFS_PARTITION_MAX_FILES 20
// Return values
#define NVS_INIT_OK 0
#define NVS_INIT_ERROR 1
#define SPIFFS_INIT_OK 0
#define SPIFFS_INIT_ERROR 1
#define READ_SPIFFS_OK 0
#define READ_SPIFFS_ERROR 1
#define WRITE_SPIFFS_OK 0
#define WRITE_SPIFFS_ERROR 1

/*** SPIFFS AUTO SAVE TASK ***/
// Configuration
#define SPIFF_AUTO_SAVE_PERIOD_MS 30000 // 30 sec

/*** ERROR HANDLER FUNCTION ***/
// Function parameters
#define CRITICAL_ERROR_GPIO 1
#define CRITICAL_ERROR_NVS 2
#define CRITICAL_ERROR_SPIFFS 3
#define CRITICAL_ERROR_JSON 4
#define CRITICAL_ERROR_PWM 5
#define CRITICAL_ERROR_EVENT_HANDLER 6
#define CRITICAL_ERROR_WIFI 7
// Error levels
#define ERROR_LEVEL_NONE 0
#define ERROR_LEVEL_WARNING 1
#define ERROR_LEVEL_WIFI 2
#define ERROR_LEVEL_CRITICAL 3

/*** FACTORY RESET FUNCTION & BLINK TASK***/
// Configuration
#define FACTORY_RESET_DEFAULT_DUTY 100
#define FACTORY_RESET_DEFAULT_ENABLE 1
#define FACTORY_RESET_DEFAULT_RGB_OUTPUTS 0
#define FACTORY_RESET_DEFAULT_W_OUTPUTS 6
#define FACTORY_RESET_DEFAULT_ENABLE_WIFI 1
// Return values
#define FACTORY_RESET_OK 0
#define FACTORY_RESET_ERROR 1
// Factory reset states
#define FACTOR_RESET_STATE_NONE 0
#define FACTORY_RESET_STATE_BEGIN 1
#define FACTORY_RESET_STATE_VALID 2
#define FACTORY_RESET_STATE_INVALID 3
#define FACTORY_RESET_STATE_RESETTING 4
#define FACTORY_RESET_STATE_ERROR 5
#define FACTORY_RESET_STATE_ABORT 6
#define FACTORY_RESET_STATE_COMPLETE 7

/***  MISCELLANEOUS FUNCTIONS ***/
// Return values
#define PATH_PARSE_OK 0
#define PATH_PARSE_ERROR 1

/*** GENERAL CONFIGURATION ***/
#define NO_CHANNELS_LIMIT 6                          // MIN: 1, MAX: max supported by esp32
#define NO_RGB_OUTPUTS_LIMIT (NO_CHANNELS_LIMIT / 3) // Maximum number of RGB outputs (= 3 channels)
#define NO_W_OUTPUTS_LIMIT NO_CHANNELS_LIMIT         // Maximum number of W outputs (= 1 channel)
#define DUTY_MAX_VALUE ((1 << PWM_RESOLUTION) - 1)   // Maximum value of DUTY parameter
#define ENABLE_MAX_VALUE 1                           // Maximum value of ENABLE parameter

#define MAX_QUERY_PARAMS 5     // Maximum number of QUERY parameters in GET request
#define MAX_POST_PARAMS 10     // Maximum number of parameters send by POST request
#define CREDENTIALS_MAX_LEN 30 // Maximum length of ssid / password

#define WIFI_MODE_SWITCH_AP_MIN_TIME_MS 5000         // Minimum button press duration to switch from or to AP wifi mode
#define WIFI_MODE_SWITCH_MIN_TIME_MS 100             // Minimum button press duration to switch STATION / NONE wifi mode
#define WIFI_AP_MODE_MAX_INACTIVITY_TIME_MS 120000UL // Maximum time of inactivity after which the AP mode should stop and switch to STATION / NONE mode
#define FACTORY_RESET_MIN_TIME_MS 10000              // Minimum button press duration to factory reset device
#define FACTORY_RESET_WINDOW_TIME_MS 5000            // Time window (after minimum button press time) when factory reset is valid

/***************************************************************************************************************/
#endif // LEDC_COMMON_H
